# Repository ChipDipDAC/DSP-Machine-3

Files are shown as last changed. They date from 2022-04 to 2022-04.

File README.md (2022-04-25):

# DSP-Machine-3<br>
<a class="link" href="https://www.chipdip.ru/catalog-show/for-you-projects?p.0=ChipDipDac"><strong>DSP Machine 3</strong></a> - стример, цифроаналоговый преобразователь ЦАП, аудиопроцессор, для микрокомпьютера Raspberry Pi.<br />
Для построения стримера вы можете использовать любой микрокомпьютер Raspberry Pi. Микрокомпьютер устанавливается на 40-пиновый разъем аудио карты. В качестве ПО используйте любой плеер или ОС образ, которых записан на микроSD карточку для Raspberry Pi. Операционные системы автоматически определяют аудиокарту ChipDip DAC и настраивают вывод звука именно на неё. В некоторых плеерах может понадобится выбрать в качестве устройства вывода звука - ChipDip DAC.<br />
<br />
- Plug and Play не требует пайки<br />
- Совместим с Raspberry Pi 4<br />
- Официальная поддержка RaspberryPi OS / Volumio3 / rAudio1 / Album Player / OpenELEC / Manjaro OS / MoOde и другими.<br />
- Высококачественный аудиопроцессор ADAU1452 и ЦАП AD1934.<br />
- Разъемы аудиовыхода: 2 x XLR (левый и правый), SPDIF, Coaxial<br />
- Встроенная EEPROM для автоматической настройки ОС (с защитой от записи).<br />
- Автоматическое переключение частот в соответствии с входными сигналами I2S.<br />
- Диапазон частот дискретизации и разрядности от 44,1кГц/16 бит до 192кГц/32 бит<br />
- Цветова индикация частот дискретизации<br />
- Совместим с ПО SigmaStudio и ChipStudio для перестройки аудиопроцессора<br />
Задать вопросы можно на форуме в разделе <a class="link" href="https://forum.chipdip.ru/index.php#chipdip-dac.39">ChipDip DAC</a>
<p><a class="galery" href="https://static.chipdip.ru/lib/992/DOC015992445.jpg">Pins DSP Machine3</a></p>

<p><a class="galery" href="https://static.chipdip.ru/lib/992/DOC015992427.jpg">Pins DSP Machine3</a></p>

<h2>Что под крышкой *</h2>

<p><a class="galery" href="https://static.chipdip.ru/lib/013/DOC016013327.jpg">Pins DSP Machine3</a></p>

<p><a class="galery" href="https://static.chipdip.ru/lib/013/DOC016013328.jpg">Pins DSP Machine3</a></p>
* Микрокомпьютер Raspberry Pi в комплект не входит.

<h2>Цветовая индикация частоты преобразования (sample rate)</h2>

<table class="user_t">
	<tbody>
		<tr>
			<td class="tcenter">
			<p><strong>Sample Rate</strong></p>
			</td>
			<td class="tcenter">
			<p><strong>Цвет индикатора</strong></p>
			</td>
		</tr>
		<tr>
			<td class="tcenter">44.1 кГц</td>
			<td class="tcenter"></td>
		</tr>
		<tr>
			<td class="tcenter">48 кГц</td>
			<td class="tcenter"></td>
		</tr>
		<tr>
			<td class="tcenter">88.2 кГц</td>
			<td class="tcenter"></td>
		</tr>
		<tr>
			<td class="tcenter">96 кГц</td>
			<td class="tcenter"></td>
		</tr>
		<tr>
			<td class="tcenter">176.4 кГц</td>
			<td class="tcenter"></td>
		</tr>
		<tr>
			<td class="tcenter">192 кГц</td>
			<td class="tcenter"></td>
		</tr>
	</tbody>
</table>

<h2>Сравнительная таблица</h2>

<table class="user_t">
	<tbody>
		<tr>
			<td class="tcenter">&nbsp;</td>
			<td class="tcenter">DSP Machine 1</td>
			<td class="tcenter">DSP Machine 2</td>
			<td class="tcenter">DSP Machine 3</td>
		</tr>
		<tr>
			<td class="tcenter">Темброблок</td>
			<td class="tcenter">+</td>
			<td class="tcenter">+</td>
			<td class="tcenter">+</td>
		</tr>
		<tr>
			<td class="tcenter">SuperBass</td>
			<td class="tcenter">+</td>
			<td class="tcenter">+</td>
			<td class="tcenter">+</td>
		</tr>
		<tr>
			<td class="tcenter">Mute</td>
			<td class="tcenter">+</td>
			<td class="tcenter">+</td>
			<td class="tcenter">+</td>
		</tr>
		<tr>
			<td class="tcenter">Блок питания</td>
			<td class="tcenter">+</td>
			<td class="tcenter">+</td>
			<td class="tcenter">+</td>
		</tr>
		<tr>
			<td class="tcenter">Корректное выключение</td>
			<td class="tcenter">+</td>
			<td class="tcenter">+</td>
			<td class="tcenter">+</td>
		</tr>
		<tr>
			<td class="tcenter">Линейный выход</td>
			<td class="tcenter">-</td>
			<td class="tcenter">+</td>
			<td class="tcenter">+</td>
		</tr>
		<tr>
			<td class="tcenter">Усилитель мощности</td>
			<td class="tcenter">+</td>
			<td class="tcenter">-</td>
			<td class="tcenter">-</td>
		</tr>
		<tr>
			<td class="tcenter">Выход SPDIF</td>
			<td class="tcenter">-</td>
			<td class="tcenter">-</td>
			<td class="tcenter">+</td>
		</tr>
		<tr>
			<td class="tcenter">Выход Toslink</td>
			<td class="tcenter">-</td>
			<td class="tcenter">-</td>
			<td class="tcenter">+</td>
		</tr>
		<tr>
			<td class="tcenter">SigmaStudio</td>
			<td class="tcenter">+</td>
			<td class="tcenter">-</td>
			<td class="tcenter">+</td>
		</tr>
		<tr>
			<td class="tcenter">PurePathStudio</td>
			<td class="tcenter">-</td>
			<td class="tcenter">+</td>
			<td class="tcenter">-</td>
		</tr>
		<tr>
			<td class="tcenter">ChipStudio</td>
			<td class="tcenter">+</td>
			<td class="tcenter">+</td>
			<td class="tcenter">+</td>
		</tr>
	</tbody>
</table>
<br />

Alt text for your video (https://youtu.be/ImISHrIo6Pk)

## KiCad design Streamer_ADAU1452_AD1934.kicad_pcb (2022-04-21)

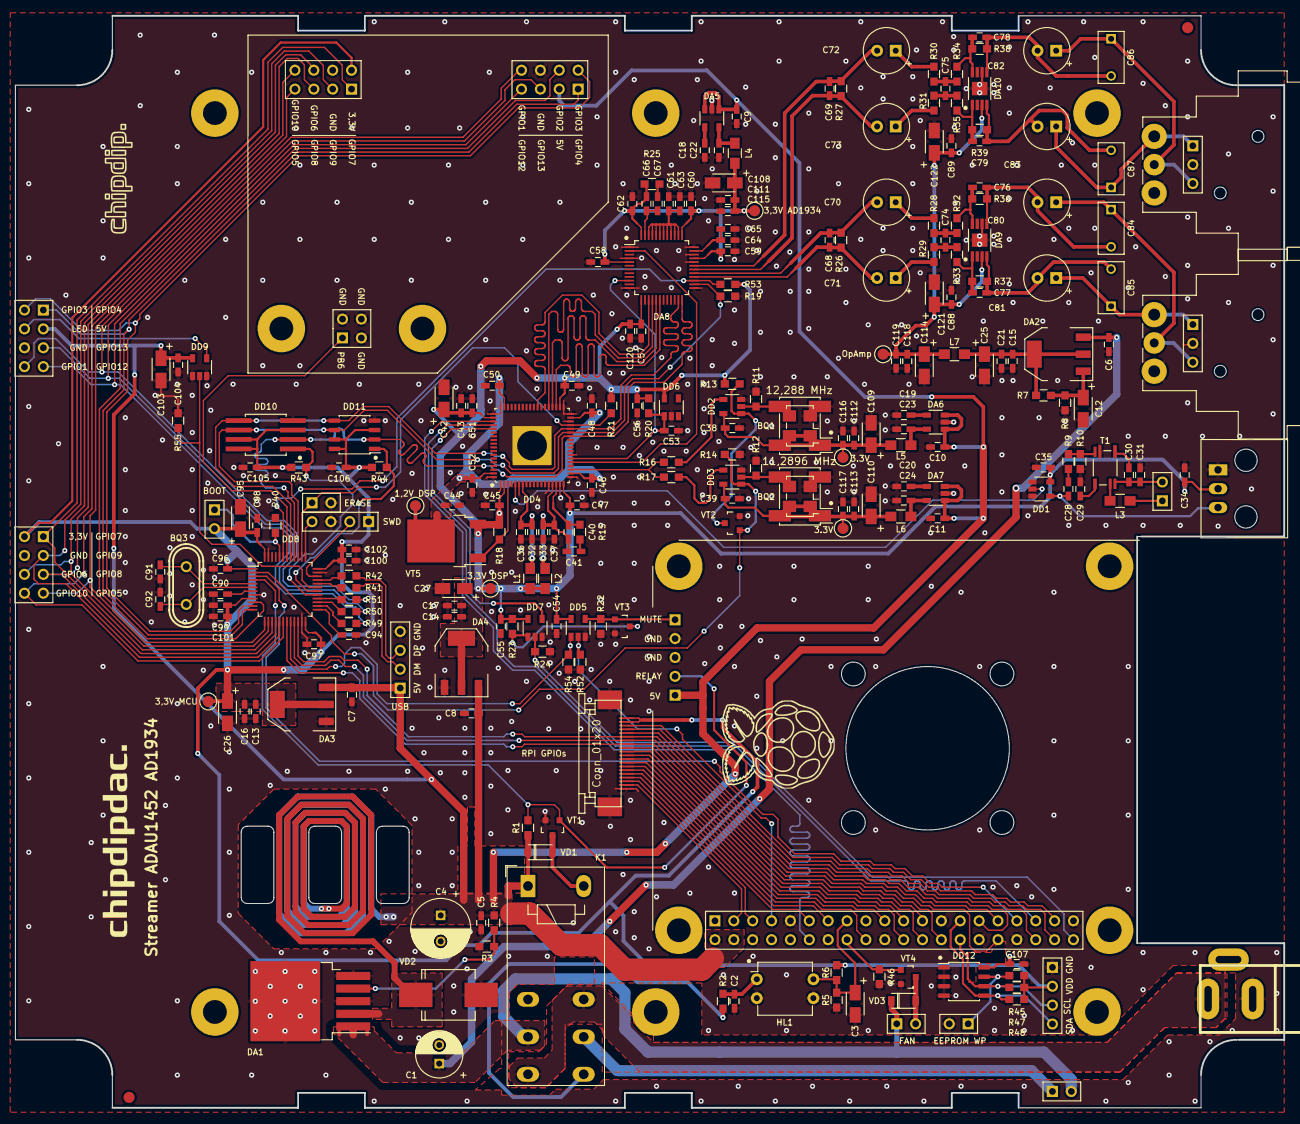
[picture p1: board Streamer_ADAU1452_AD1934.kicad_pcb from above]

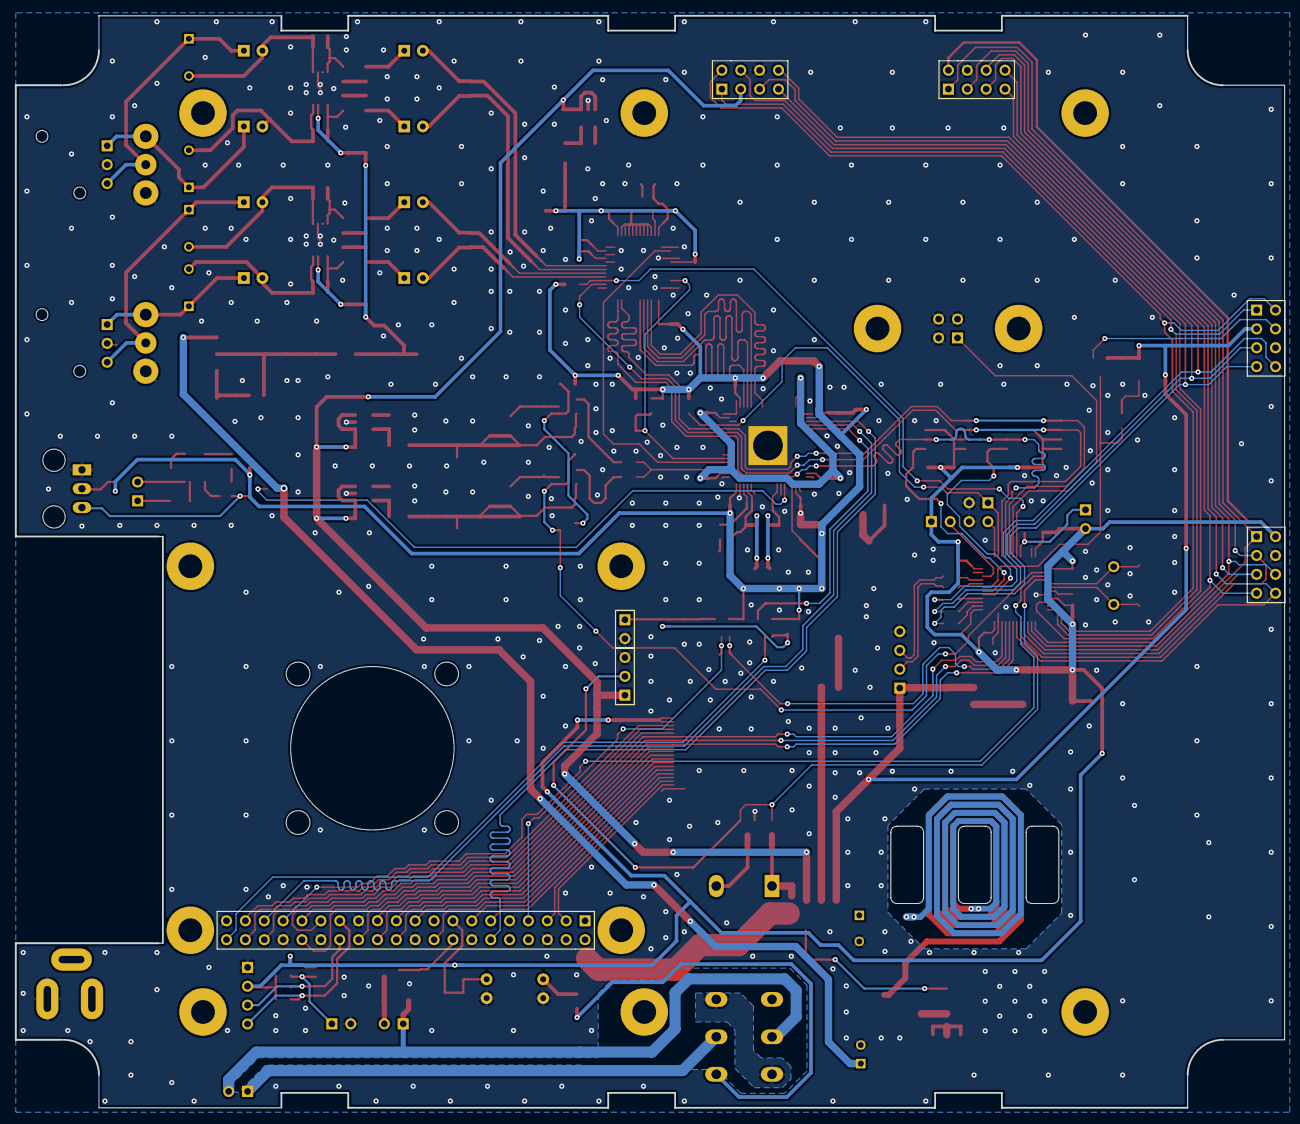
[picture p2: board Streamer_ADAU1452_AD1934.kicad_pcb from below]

Board: 2 copper layers, 170.8 x 147.0 mm, 252 parts (7 on the bottom side), 148 nets.

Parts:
BQ1: 12,288MHz; Oscillator_SMD_Fordahl_DFAS2-4Pin_7.3x5.1mm_HandSoldering
BQ2: 11,2896MHz; Oscillator_SMD_Fordahl_DFAS2-4Pin_7.3x5.1mm_HandSoldering
BQ3: 8 Mhz; CRYST_hc-49u_mm
BQ4: 12,288MHz; Oscillator_SMD_EuroQuartz_XO53-4Pin_5.0x3.2mm_HandSoldering
BQ5: 11,2896MHz; Oscillator_SMD_EuroQuartz_XO53-4Pin_5.0x3.2mm_HandSoldering
C1: 100u; C_Radial_D6.3_L11.2_P2.5
C2, C32, C33, C43, C44, C63, C65, C120: 10u; C_0603_HandSoldering
C3, C12, C25, C26, C27, C42, C95, C103, C108, C109, C110, C114, C121, C122: 4.7u; TantalC_SizeA_EIA-3216_mm
C4: 1000u; C_Radial_D8_L11.5_P3.5
C5, C6, C7, C8, C9, C10, C11, C13, C14, C15, C16, C17, C21, C22, C23, C24, C96, C101, C102, C111, C112, C113, C118: 2.2u; C_0603_HandSoldering
C18, C19, C20, C28: 0.01u; C_0603_HandSoldering
C29, C30, C34, C35, C36, C37, C38, C39, C45, C46, C47, C48, C49, C50, C51, C52, C53, C54, C55, C56, C57, C58, C59, C60, C61, C62, C64, C88, C89, C90, C97, C98, C99, C100, C104, C105, C106, C107, C115, C116, C117, C119: 0.1u; C_0603_HandSoldering
C31, C91, C92: 22p; C_0603_HandSoldering
C40, C76, C77, C78, C79: 150p; C_0603_HandSoldering
C41, C67: 5n6; C_0603_HandSoldering
C66: 390p; C_0603_HandSoldering
C68, C69: 1n; C_0603_HandSoldering
C70, C71, C72, C73, C80, C81, C82, C83: 10u; CP_Radial_Tantal_D6.0mm_P2.50mm
C74, C75: 470p; C_0603_HandSoldering
C84, C85, C86, C87: 0.47u; C_Rect_L7_W3.5_P5
C94: 47p; C_0603_HandSoldering
DA1: LM2596S-ADJ; TO-263-5_TabPin3
DA2, DA3, DA4: LM1117-3.3; SOT-223
DA5, DA6, DA7: LP2985-3.3; SOT-23-5_mm
DA8: AD1934; LQFP-48_7x7mm_Pitch0.5mm
DA9, DA10: OPA1632; VSSOP-8
DD1, DD2, DD3, DD7: 74LVC1G125; SOT-23-5_mm
DD4: ADAU1452; LFCSP72_10x10_EP_Handsoldering
DD5: NC7S08M5X; SOT-23-5_mm
DD6: ADM6316; SOT-23-5_mm
DD8: STM32L433CCTx; LQFP-48_7x7mm_Pitch0.5mm
DD9: MC74VHC1GT125; SOT-23-5_mm
DD10: 25LCxxx; SOIC-8_combo_Pitch1.27mm
DD11: 25LCxxx; SOIC-8_3.9x4.9mm_Pitch1.27mm
DD12: 24LC64; SOIC-8_3.9x4.9mm_Pitch1.27mm
HL1: P814; DIP-4_W7.62mm
K1: RTE2xxxx; Relay_DPDT_Schrack-RT2-FormC_RM5mm
L1, L2, L3, L4, L5, L6, L7: L; R_0805_HandSoldering
P3, P4, P5, P6, P7, P8, P9: Conn_01x01; Measurement_Point_Round-SMD-Pad_Small
R1, R6, R7, R8, R11, R12, R13, R14, R19, R20, R21, R22, R23, R24, R36, R37, R38, R39, R40, R43, R44, R45, R46, R49, R50, R51, R52, R53, R54, R55: 10k; R_0603
R2: 2k; R_0603
R3, R18: 1k; R_0603
R4: 3k; R_0603
R5: 15k; R_0603
R9: 470R; R_0603
R10: 110R; R_0603
R15: 4k32; R_0603
R16, R17: 51R; R_0603
R25: 560; R_0603
R26, R27: 100k; R_0603
R28, R29, R30, R31, R32, R33, R34, R35: 2k2; R_0603
R41, R42: 22; R_0603
R47, R48: 4k7; R_0603
T1: ALT4532M; ALT4532
VD1, VD3: D; SOD-123
VD2: D_Schottky; DIODE_SMC_Handsoldering
VT1, VT2, VT3, VT4: BSS138; SOT-23_mm
VT5: STD2805; TO-252-2
XP1, XP14, XP15: Conn_01x03; Pin_Header_Straight_1x03_mm
XP2: Conn_01x03; Optic_FCR6842031T
XP3, XP6, XP8, XP9, XP11, XP13: Conn_01x02; Pin_Header_Straight_1x02_mm
XP4, XP5: XLR3; Jack_XLR_Neutrik_NC3MAAH-1_Horizontal
XP7, XP10, XP12: Conn_01x04; Pin_Header_Straight_1x04_mm
XS1: Conn_01x03; JACK_DC
XS2: Conn_01x02; Pin_Header_Straight_1x02_mm
XS3: Conn_02x20_Odd_Even; Pin_Header_Straight_2x20_mm
XS4, XS5, XS7, XS8: Conn_02x04_Odd_Even; Pin_Header_Straight_2x04_mm
XS6: Conn_01x20; CONN20
XS9: Conn_02x02_Odd_Even; Pin_Header_Straight_2x02_mm

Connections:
5V: C4.1, C5.1, C7.1, C8.1, C9.1, C10.1, C11.1, C103.1, C104.1, DA1.2, DA3.3, DA4.3, DA5.1, DA5.3, DA6.1, DA6.3, DA7.1, DA7.3, DD9.5, K1.A1, R1.1, R4.1, VD1.1, VD2.1, XP1.1, XP10.1, XS3.2, XS3.4, XS5.3, XS8.3
12V: K1.14, K1.22, XS1.1
BCLK: DD4.57, XS3.12
BOOT: DD8.44, R40.1, XP6.1
DATA: DD7.2, R24.2, XS3.40
DSP_BCLK0: DA8.17, DD4.40
DSP_LR0: DA8.18, DD4.39
DSP_RST: C53.1, DA8.10, DD4.24, DD6.1, R20.2
DSP_SDATA0: DA8.16, DD4.41
DSP_SDATA1: DA8.15, DD4.44
DVDD: C44.1, C46.1, C48.1, C50.1, C52.1, DD4.20, DD4.35, DD4.53, DD4.71, P6.1, VT5.2
FAN: R46.1, VT4.1, XS3.16
GEN_SEL: DD3.1, DD8.2, R14.1, VT2.1
GND: BQ1.2, BQ2.2, BQ4.2, BQ5.2, C1.2, C2.2, C3.2, C4.2, C5.2, C6.2, C7.2, C8.2, C9.2, C10.2, C11.2, C12.2, C13.2, C14.2, C15.2, C16.2, C17.2, C18.2, C19.2, C20.2, C21.2, C22.2, C23.2, C24.2, C25.2, C26.2, C27.2, C29.2, C31.2, C32.2, C33.2, C34.2, C35.2, C36.2, C37.2, C38.2, C39.2, C42.2, C43.2, C44.2, C45.2, C46.2, C47.2, C48.2, C49.2, C50.2, C51.2, C52.2, C53.2, C54.2, C55.2, C56.2, C57.2, C58.2, C59.2, C60.2, C61.2, C62.2, C63.2, C64.2, C65.2, C88.1, C89.1, C90.2, C91.2, C92.2, C94.2, C95.2, C96.2, C97.2, C98.2, C99.2, C100.2, C101.2, C102.2, C103.2, C104.2, C105.2, C106.2, C107.2, C108.2, C109.2, C110.2, C111.2, C112.2, C113.2, C114.2, C115.2, C116.2, C117.2, C118.2, C119.2, C120.2, C121.2, C122.2, DA1.3, DA1.5, DA3.1, DA4.1, DA5.2, DA6.2, DA7.2, DA8.1, DA8.4, DA8.12, DA8.25, DA8.32, DA8.34, DA8.36, DA9.6, DA9.9, DA10.6, DA10.9, DD1.1, DD1.3, DD2.3, DD3.3, DD4.1, DD4.6, DD4.14, DD4.17, DD4.19, DD4.25, DD4.34, DD4.36, DD4.37, DD4.54, DD4.55, DD4.72, DD4.73, DD5.3, DD6.2, DD7.3, DD8.8, DD8.23, DD8.35, DD8.47, DD9.1, DD9.3, DD10.4, DD11.4, DD12.1, DD12.2, DD12.3, DD12.4, HL1.2, HL1.3, R3.1, R5.2, R8.2, R10.2, R11.1, R12.1, R14.2, R19.1, R22.2, R24.1, R40.2, R46.2, R52.1, R54.1, R55.2, T1.2, VD2.2, VT1.2, VT2.2, VT3.2, VT4.2, XP1.3, XP2.1, XP3.2, XP4.1, XP5.1, XP7.3, XP8.2, XP10.4, XP11.2, XP12.1, XP14.2, XP15.2, XS1.2, XS3.6, XS3.9, XS3.14, XS3.20, XS3.25, XS3.30, XS3.34, XS3.39, XS4.4, XS5.6, XS6.20, XS7.4, XS8.6, XS9.2, XS9.3, XS9.4
GPIO0: DA8.27, DD8.43, R53.2
GPIO1: R51.1, XS5.8, XS8.8
GPIO2: DD8.10, XS8.4
GPIO3: DD8.11, XS5.2, XS8.2
GPIO4: DD8.12, XS5.1, XS8.1
GPIO5: DD8.13, XS4.7, XS7.7
GPIO6: DD8.14, XS4.6, XS7.6
GPIO7: DD8.15, XS4.1, XS7.1
GPIO8: DD8.16, XS4.5, XS7.5
GPIO9: DD8.17, XS4.3, XS7.3
GPIO10: DD8.18, XS4.8, XS7.8
GPIO12: R49.1, XS5.7, XS8.7
GPIO13: R50.1, XS5.5, XS8.5
ID_SCL: DD12.6, R47.2, XP12.3, XS3.28
ID_SDA: DD12.5, R48.2, XP12.4, XS3.27
LED_OUT: DD9.4, XS5.4
LR: DD4.58, XS3.35
MCLK_OUT: DA8.2, DD4.23
MUTE: DD5.2, R52.2, XS3.7
MUTE2: DD5.1, DD8.20, R54.2
MUTE_OUT: DA9.7, DA10.7, DD5.4, R22.1, VT3.1, XP3.1
unnamed: BQ1.3, BQ4.3, DD2.2, R11.2
unnamed: BQ2.3, BQ5.3, DD3.2, R12.2
unnamed: BQ3.1, C91.1, DD8.5
unnamed: BQ3.2, C92.1, DD8.6
unnamed: C2.1, HL1.1, R2.2
unnamed: C12.1, DA2.1, R7.2, R8.1
unnamed: C15.1, C21.1, C25.1, DA2.2, DA2.4, L7.1, R7.1
unnamed: C18.1, DA5.4
unnamed: C19.1, DA6.4
unnamed: C20.1, DA7.4
unnamed: C22.1, DA5.5, L4.1
unnamed: C23.1, DA6.5, L5.1
unnamed: C24.1, DA7.5, L6.1
unnamed: C28.1, R9.2
unnamed: C29.1, T1.6
unnamed: C30.1, T1.3
unnamed: C30.2, C31.1, T1.4, XS2.2
unnamed: C32.1, C36.1, DD4.7, L1.2
unnamed: C33.1, C37.1, C40.1, C41.1, DD4.15, L2.2
unnamed: C40.2, DD4.16, R15.2
unnamed: C41.2, R15.1
unnamed: C61.1, C63.1, DA8.38, DA8.39, DA8.40, DA8.41, DA8.42, DA8.43, DA8.44, DA8.45, DA8.46
unnamed: C64.1, C65.1, DA8.35
unnamed: C66.1, C67.1, DA8.47
unnamed: C67.2, R25.1
unnamed: C68.1, C70.2, DA8.29, R26.1
unnamed: C68.2, C71.2, DA8.28, R26.2
unnamed: C69.1, C72.2, DA8.31, R27.1
unnamed: C69.2, C73.2, DA8.30, R27.2
unnamed: C70.1, R28.1
unnamed: C71.1, R29.1
unnamed: C72.1, R30.1
unnamed: C73.1, R31.1
unnamed: C74.1, R28.2, R32.1
unnamed: C74.2, R29.2, R33.1
unnamed: C75.1, R30.2, R34.1
unnamed: C75.2, R31.2, R35.1
unnamed: C76.1, C80.2, C84.2, DA9.5, R36.2
unnamed: C76.2, DA9.8, R32.2, R36.1
unnamed: C77.1, C81.2, C85.2, DA9.4, R37.2
unnamed: C77.2, DA9.1, R33.2, R37.1
unnamed: C78.1, C82.2, C86.2, DA10.5, R38.2
unnamed: C78.2, DA10.8, R34.2, R38.1
unnamed: C79.1, C83.2, C87.2, DA10.4, R39.2
unnamed: C79.2, DA10.1, R35.2, R39.1
unnamed: C80.1, C84.1, XP4.3, XP14.3
unnamed: C81.1, C85.1, XP4.2, XP14.1
unnamed: C82.1, C86.1, XP5.3, XP15.3
unnamed: C83.1, C87.1, XP5.2, XP15.1
unnamed: C94.1, DD8.25
unnamed: DA1.4, R3.2, R4.2
unnamed: DD1.2, DD4.5
unnamed: DD2.1, R13.2, VT2.3
unnamed: DD2.4, R16.2
unnamed: DD3.4, R17.2
unnamed: DD4.3, R18.2, VT5.1
unnamed: DD4.21, R16.1, R17.1
unnamed: DD7.1, R23.2, VT3.3
unnamed: DD8.26, R49.2
unnamed: DD8.27, R50.2
unnamed: DD8.28, R51.2
unnamed: DD8.31, DD9.2, R55.1
unnamed: DD8.32, R41.1
unnamed: DD8.33, R42.1
unnamed: DD12.7, R45.2, XP8.1
unnamed: K1.21, XP13.1
unnamed: K1.24, R2.1
unnamed: K1.A2, VD1.2, VT1.3
unnamed: L3.1, T1.5
unnamed: L3.2, XS2.1
unnamed: R9.1, R10.1, T1.1
unnamed: VD3.2, VT4.3, XP9.2
ON_OFF: C3.1, HL1.4, R5.1, R6.2, XS3.15
PB6: DD8.42, XS9.1
PWR_EVENT: DD8.3, XS3.33
RAS_GPIO2: XS3.3, XS6.19
RAS_GPIO3: XS3.5, XS6.18
RAS_GPIO7: XS3.26, XS6.9
RAS_GPIO8: XS3.24, XS6.11
RAS_GPIO9: XS3.21, XS6.12
RAS_GPIO10: XS3.19, XS6.14
RAS_GPIO11: XS3.23, XS6.10
RAS_GPIO16: XS3.36, XS6.5
RAS_GPIO17: XS3.11, XS6.17
RAS_GPIO20: XS3.38, XS6.4
RAS_GPIO25: XS3.22, XS6.13
RAS_GPIO26: XS3.37, XS6.3
RELAY: DD8.4, R1.2, VT1.1, XP1.2
RES0: XS3.18, XS6.15
RES1: XS3.13, XS6.16
RST: C90.1, DD8.7
SDATA_IN0: DD4.59, DD7.4
SPDIF_OUT: C28.2, DD1.4, XP2.3
SPI1_MISO: DA8.24, DD4.30, DD8.40, DD10.2, DD11.2
SPI1_MOSI: DA8.23, DD4.32, DD8.41, DD10.5, DD11.5
SPI1_NSS1: DD4.33, DD8.38, R21.2, XP11.1
SPI1_NSS2: DD8.29, DD10.1, R43.2
SPI1_NSS3: DD8.30, DD11.1, R44.2
SPI1_SCK: DA8.26, DD4.31, DD8.39, DD10.6, DD11.6, R19.2
SR0: DD8.22, XS3.29, XS6.6
SR1: DD8.21, XS3.31, XS6.7
SR2: DD8.19, XS3.32, XS6.8
SWCLK: DD8.37, XP7.4
SWDIO: DD8.34, XP7.2
USB_DM: R41.2, XP10.2
USB_DP: R42.2, XP10.3
VDD: C13.1, C16.1, C26.1, C95.1, C96.1, C97.1, C98.1, C99.1, C100.1, C101.1, C102.1, C105.1, C106.1, C107.1, DA3.2, DA3.4, DD8.1, DD8.9, DD8.24, DD8.36, DD8.48, DD10.3, DD10.7, DD10.8, DD11.3, DD11.7, DD11.8, DD12.8, P4.1, R6.1, R43.1, R44.1, R45.1, R47.1, R48.1, XP6.2, XP7.1, XP12.2, XS4.2, XS6.1, XS6.2, XS7.2
VDDA: C58.1, C59.1, C60.1, C62.1, C66.2, C108.1, C111.1, C115.1, DA8.5, DA8.33, DA8.37, DA8.48, L4.2, P7.1, R25.2
VDD_AOUT: C88.2, C89.2, C114.1, C118.1, C119.1, C121.1, C122.1, DA9.3, DA10.3, L7.2, P3.1
VDD_DSP: C14.1, C17.1, C27.1, C34.1, C35.1, C42.1, C43.1, C45.1, C47.1, C49.1, C51.1, C54.1, C55.1, C56.1, C57.1, C120.1, DA4.2, DA4.4, DA8.13, DD1.5, DD4.2, DD4.18, DD4.38, DD4.56, DD5.5, DD6.5, DD7.5, L1.1, L2.1, P5.1, R13.1, R18.1, R20.1, R21.1, R23.1, R53.1, VT5.3, XP2.2
VDD_GEN1: BQ2.1, BQ2.4, BQ5.1, BQ5.4, C39.1, C110.1, C113.1, C117.1, DD3.5, L6.2, P9.1
VDD_GEN2: BQ1.1, BQ1.4, BQ4.1, BQ4.4, C38.1, C109.1, C112.1, C116.1, DD2.5, L5.2, P8.1
VIN: C1.1, C6.1, DA1.1, DA2.3, K1.11, VD3.1, XP9.1, XP13.2

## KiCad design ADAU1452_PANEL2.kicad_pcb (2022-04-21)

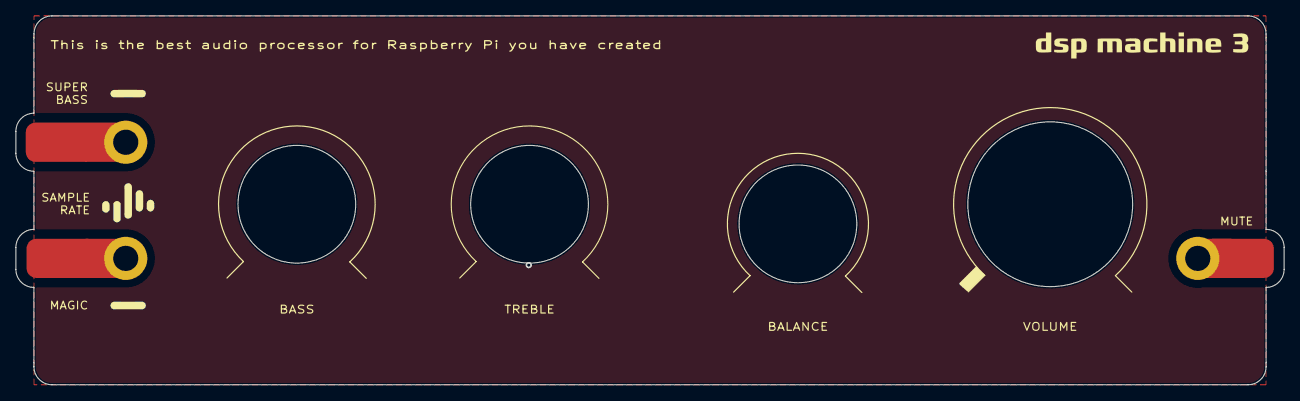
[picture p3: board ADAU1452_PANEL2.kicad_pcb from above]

Board: 2 copper layers, 161.6 x 47.0 mm, 7 parts (1 on the bottom side), 3 nets.

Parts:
J1, J2, J3: Conn_01x01_Male; TestPoint_THTPad_D2.0mm_Drill1.0mm
TP1, TP1#2, TP3, TP6: TestPoint; TestPoint_Pad_4.0x4.0mm

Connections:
unnamed: J1.1, TP1.1
unnamed: J2.1, TP1#2.1
unnamed: J3.1, TP6.1
